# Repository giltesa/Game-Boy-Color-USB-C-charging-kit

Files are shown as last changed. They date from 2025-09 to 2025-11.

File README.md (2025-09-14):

# Game Boy Color USB-C Charging Kit

The **Game Boy Color USB-C Charging Kit** is a circuit that allows you to charge a **Nintendo Game Boy Color** by **USB-C** and use a **Li-ion** battery instead of AA batteries.

This circuit includes the famous **TP4056** and **DW01A**. The first one is the device in charge of charging the battery, and the second one is protecting the lifetime of the battery of the over-discharge.

This kit includes two boards. If you want to install it easy, it's enough with the main board which doesn't need any cable for working. However, if you want to have the status LEDs in the same place as the original status LED, then you will need to solder the second board and joint both with 3 cables. You can choose the best option for you.

This is the maind board:

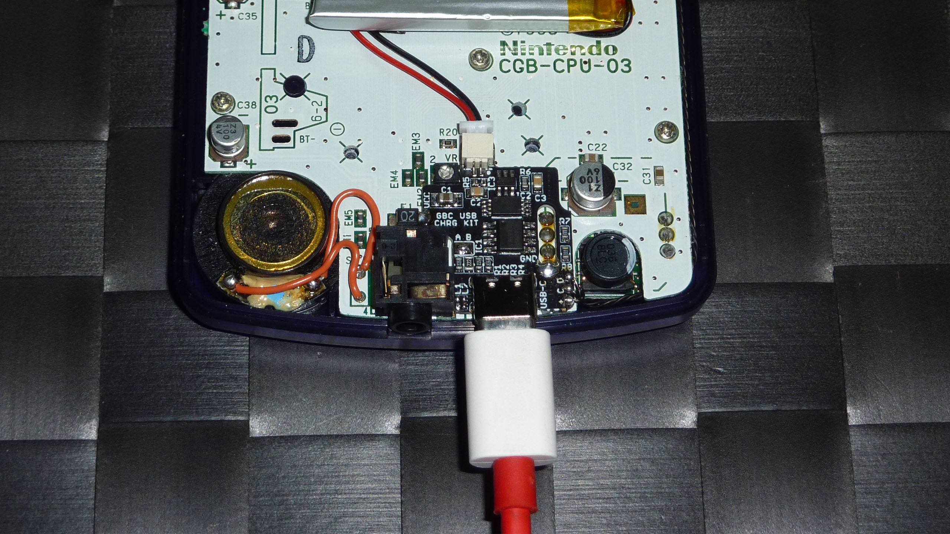
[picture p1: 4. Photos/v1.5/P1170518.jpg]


And this one is the LED board:

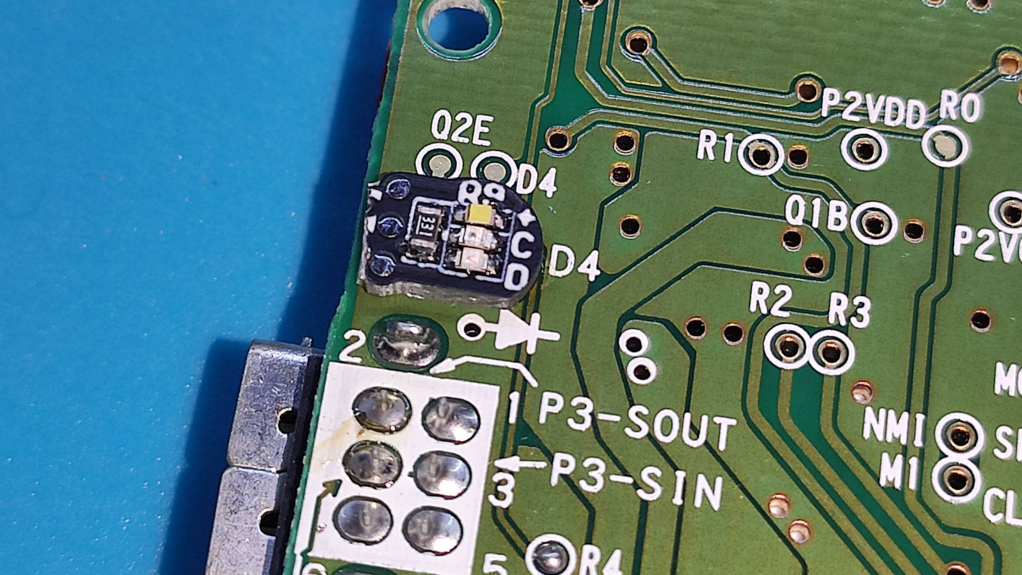
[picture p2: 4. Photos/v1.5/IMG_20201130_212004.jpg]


## Youtube:

Game Boy Color USB-C Charging Kit (Installation)

GBC (https://www.youtube.com/watch?v=6jVHuUIQE74)

A small demostration about how this works:

*(red light = charging, green light = finish to charge, white = GBC is power on)*

GBC (https://www.youtube.com/watch?v=vwyqkQ_spI8)

Battery test: 1500 mAh = 8h 40m

GBC (https://www.youtube.com/watch?v=jIQpzhPCvvI)

## Would you like it?

https://shop.giltesa.com/product/game-boy-color-usb-c-charging-kit/

## More

- [giltesa.com](https://giltesa.com "giltesa.com")
- [twitter.com](https://twitter.com/giltesa "twitter.com")

## License

This project is licensed under a **Creative Commons** license:
**[Attribution-NonCommercial-ShareAlike 4.0 International (CC BY-NC-SA 4.0) ](https://creativecommons.org/licenses/by-nc-sa/4.0/)**

Check the [LICENSE.md](LICENSE.md) for more information.

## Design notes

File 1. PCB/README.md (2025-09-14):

# Source Code Availability Notice

The source code for the electronic circuits previously shared in this repository is **no longer publicly available**.

This decision has been made due to repeated misuse of the shared materials by third parties who have used the code to manufacture and sell products derived from this work for commercial gain, in violation of the license under which it was originally shared.

The original license explicitly **prohibits commercial use** of this work without proper authorization. Unfortunately, the terms of the license were not respected, which undermines the purpose of sharing the source code and the trust of the community.

Thank you for your understanding and respect for intellectual property rights.

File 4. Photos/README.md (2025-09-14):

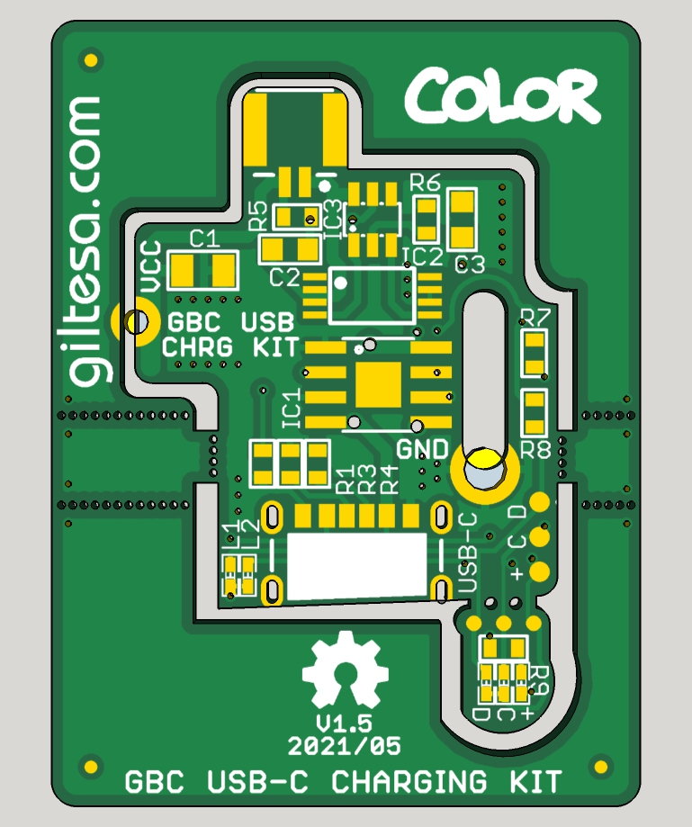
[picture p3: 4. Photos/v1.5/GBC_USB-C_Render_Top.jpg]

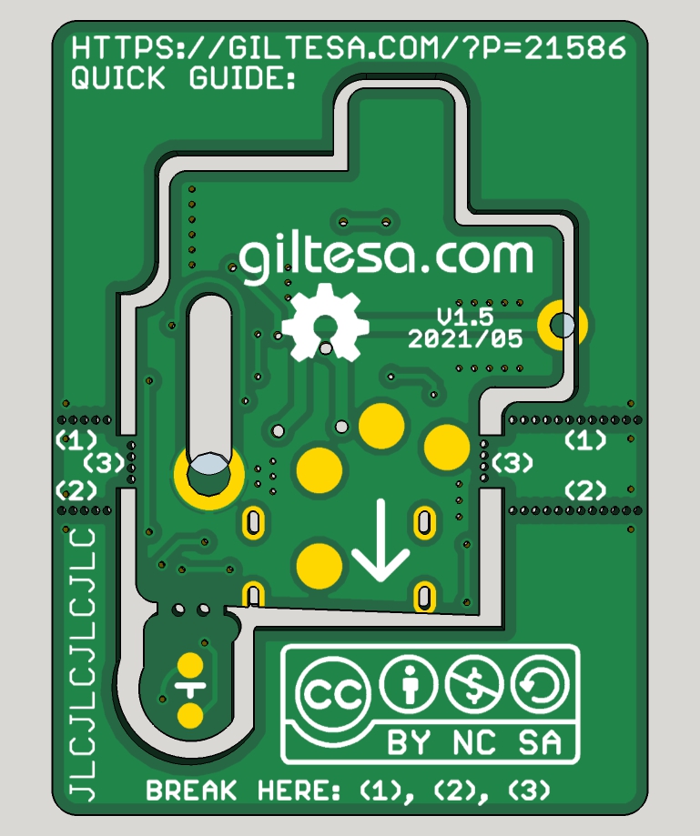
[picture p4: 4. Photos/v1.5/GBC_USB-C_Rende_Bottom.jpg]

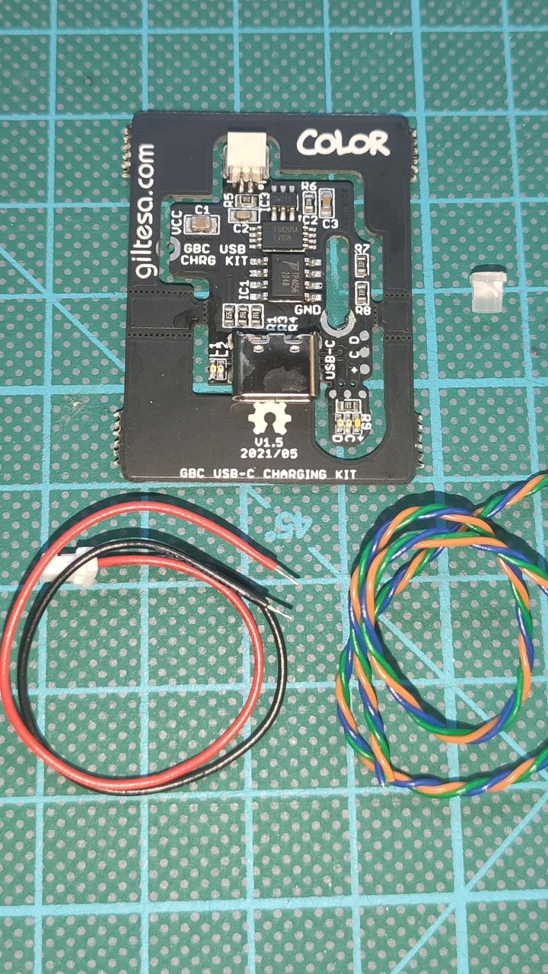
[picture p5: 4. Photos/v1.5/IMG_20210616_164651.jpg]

GBC
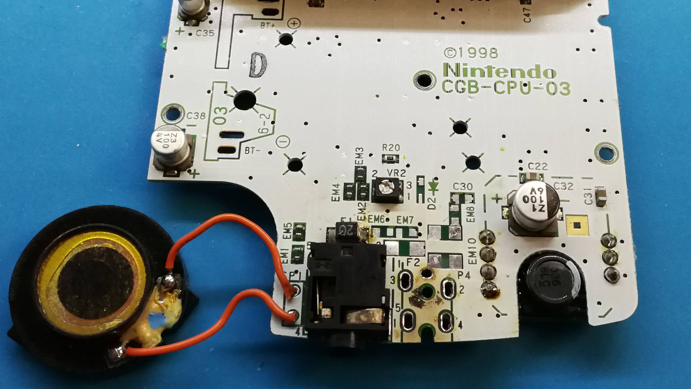
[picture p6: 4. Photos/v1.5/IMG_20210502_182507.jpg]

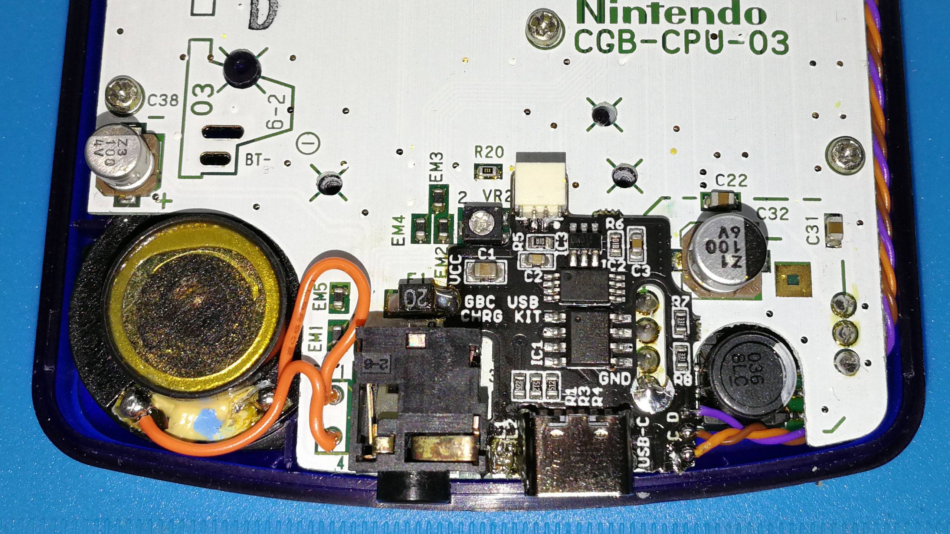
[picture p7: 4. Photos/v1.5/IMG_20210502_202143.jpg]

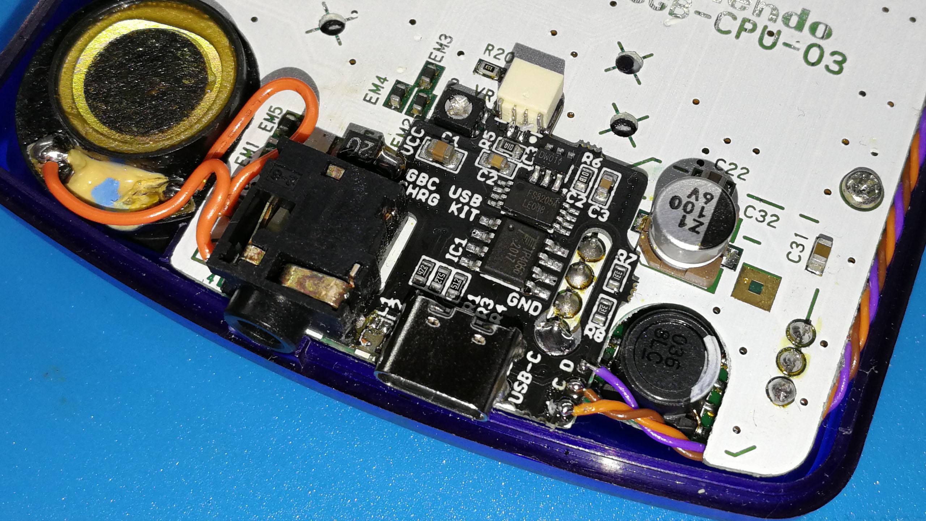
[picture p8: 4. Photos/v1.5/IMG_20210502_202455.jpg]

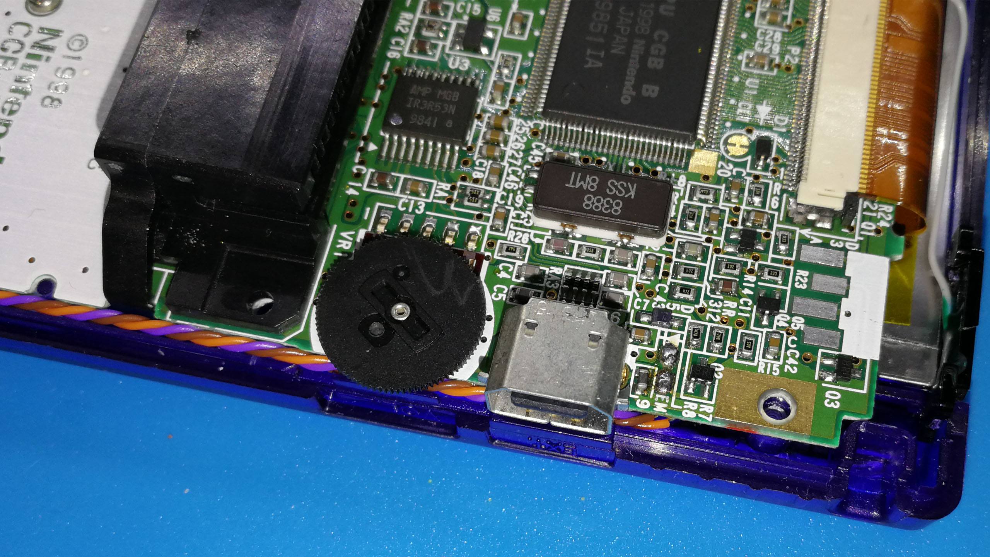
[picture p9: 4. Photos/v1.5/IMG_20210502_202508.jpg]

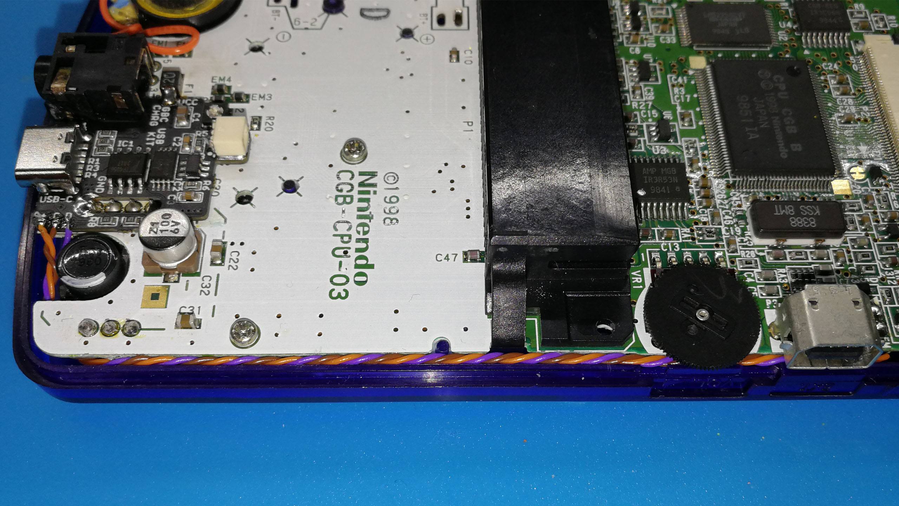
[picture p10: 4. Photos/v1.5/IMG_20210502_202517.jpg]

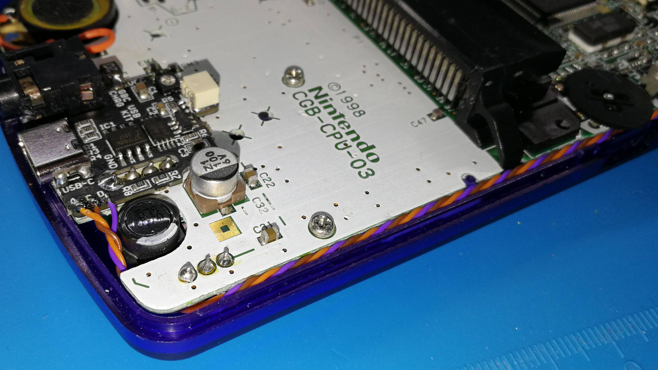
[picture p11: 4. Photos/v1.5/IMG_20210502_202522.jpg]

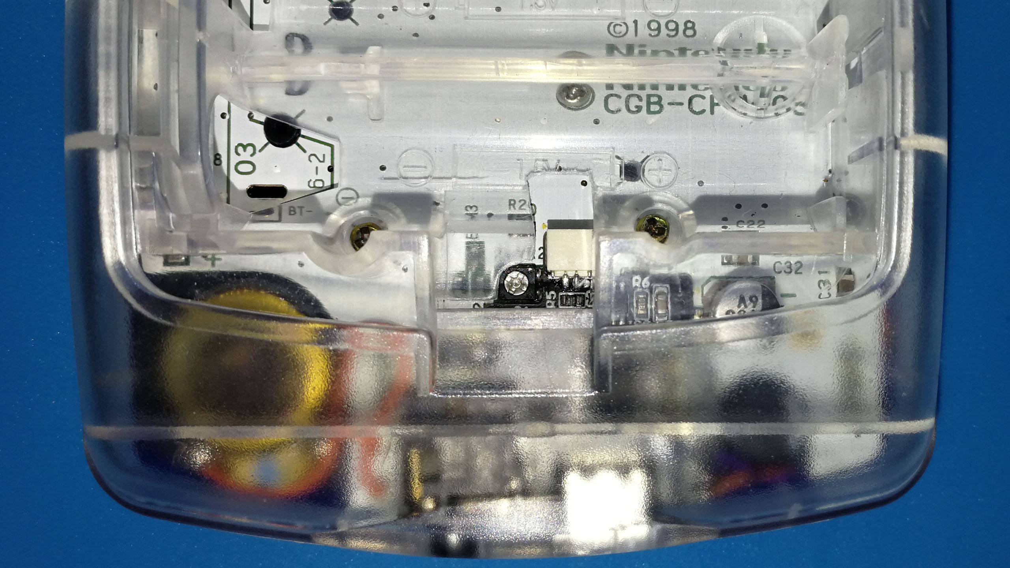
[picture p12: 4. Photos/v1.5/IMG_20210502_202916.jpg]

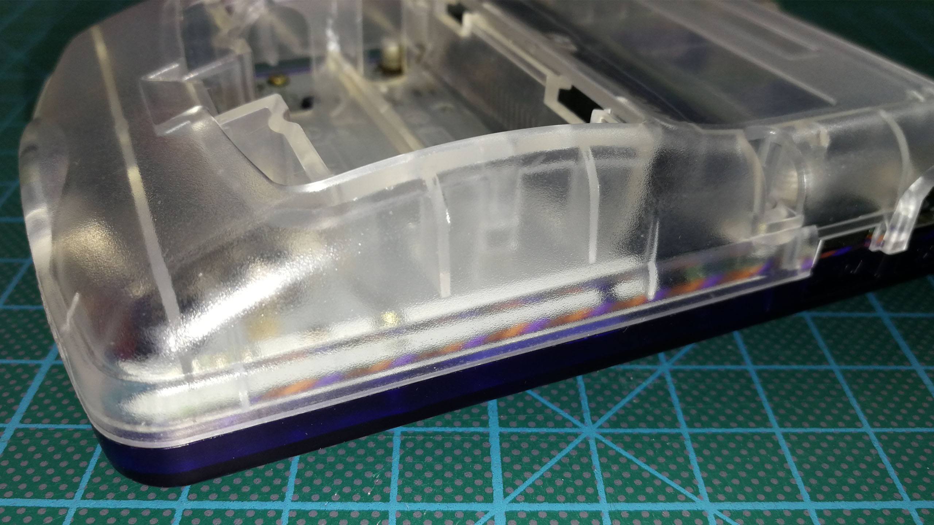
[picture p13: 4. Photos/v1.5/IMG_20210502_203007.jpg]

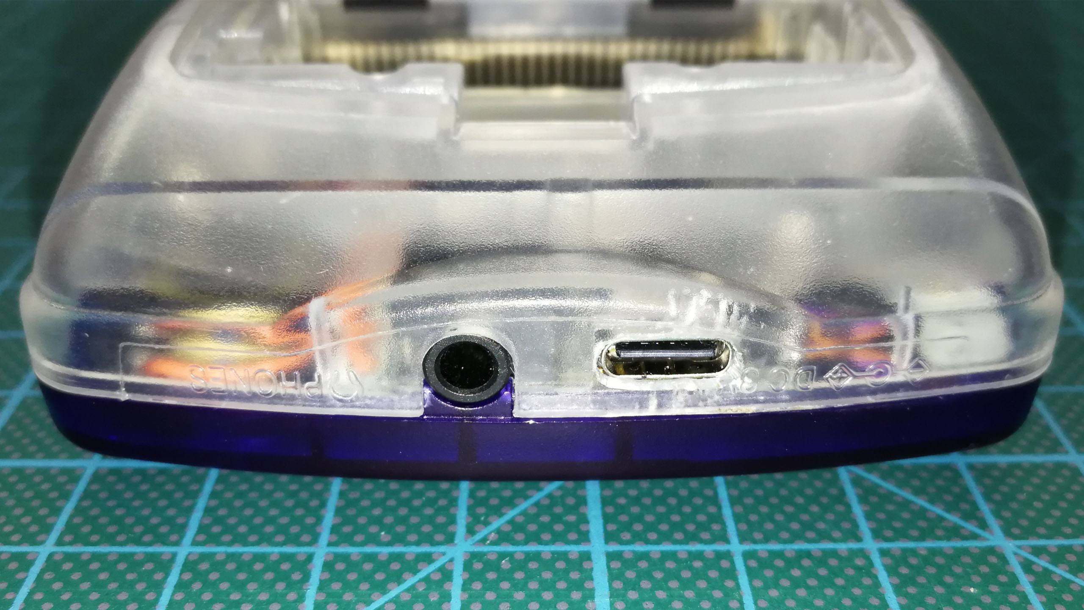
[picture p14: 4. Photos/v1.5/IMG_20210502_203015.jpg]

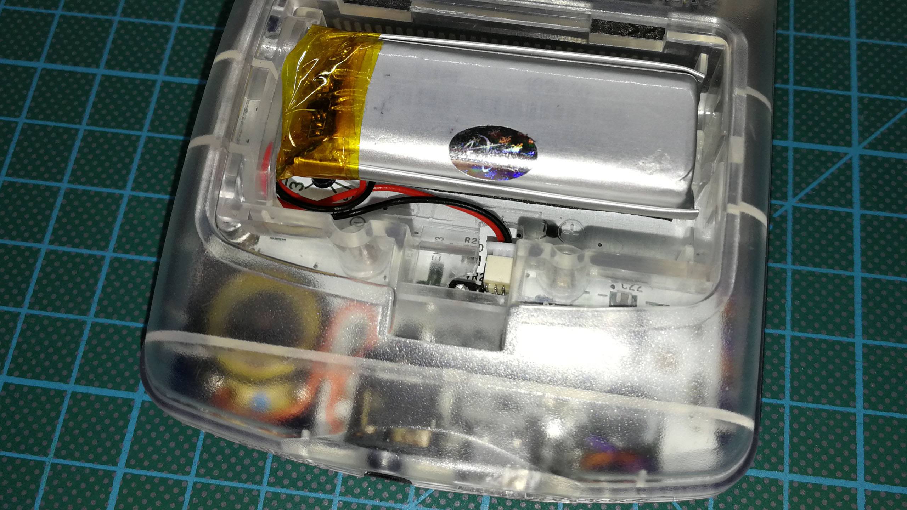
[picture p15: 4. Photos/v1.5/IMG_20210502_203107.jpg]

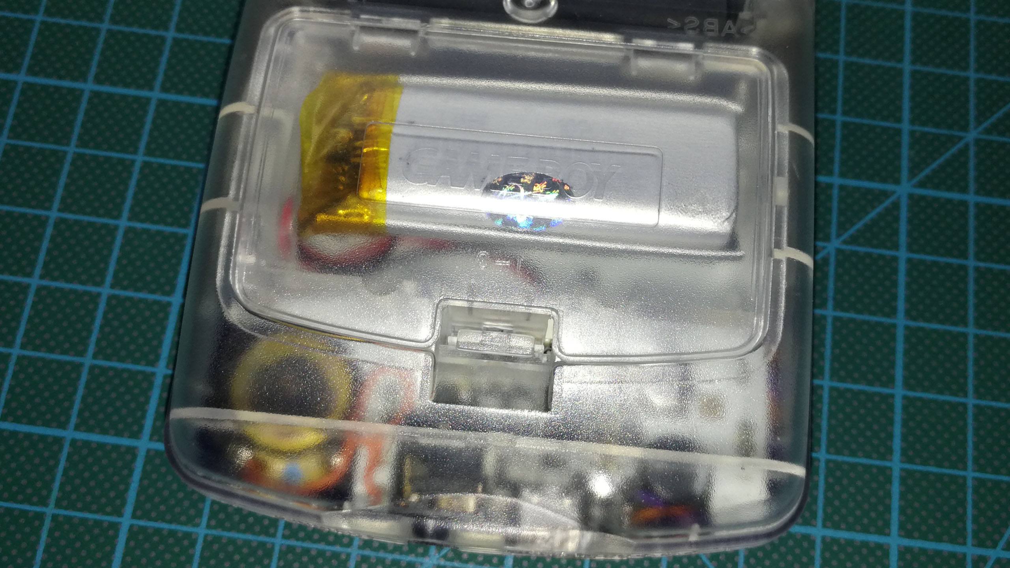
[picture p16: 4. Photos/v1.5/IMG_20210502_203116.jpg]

GBC

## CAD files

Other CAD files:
2. Renders, 3D models/GBC USB-C Charging Kit v1.6 frame.skp
2. Renders, 3D models/GBC USB-C Charging Kit v1.6.skp
2. Renders, 3D models/GBC USB-C Charging Kit v1.7 - Board.skp
2. Renders, 3D models/GBC USB-C Charging Kit v1.7-Black.skp
2. Renders, 3D models/GBC USB-C Charging Kit v1.7.skp
2. Renders, 3D models/GBC USB-C Charging Kit v2.0-Black.skp

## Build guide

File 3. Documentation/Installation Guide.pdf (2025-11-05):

# USB-C charging kit for GAME BOY COLOR

PRODUCT v2.0+

HTTPS://SHOP.GILTESA.COM/PRODUCT/GAME-BOY-COLOR-USB-C-CHARGING-KIT

# PLEASE READ THROUGH THESE INSTRUCTIONS

ENTIRELY BEFORE ATTEMPTING TO INSTALL.

# WARNING: IF YOU ARE NOT COMFORTABLE WITH SOLDERING, OR PERFORMING ANY STEP IN THIS

GUIDE, DO NOT PERFORM THE INSTALL YOURSELF.

# FIND SOMEONE WHO IS COMFORTABLE TO DO IT FOR

YOU.

INDEX

# Description

The Game Boy Color USB-C Charging Kit is a circuit that allows to charge a Nintendo Game Boy Color by USB-C and use a Li-ion battery instead of AA batteries.

# FEATURES

- Exact shape for Game Boy Color.
- Li-Ion battery charger by USB-C with protection for charging level and over discharge.
- Integrated LED indicators on the main board, next to the USB-C, for charging battery (red) and full battery (green).
- External LED indicators board for playing (white), charging battery (red) and full battery (green). The installation is optional.

# INCLUDED

- 1 frame panel which includes the two boards:
- Main board.
- Light board.
- 1 Battery cable.
- 1 Cable of 2 wires for connecting the light board.
- 1 Light diffuser pipe.

# Recommended / REQUIRED (NOT INCLUDED)

- 3.7V li-ion battery (for example 102050 (https://www.aliexpress.com/item/4000036271843.html) or 123048) (https://www.aliexpress.com/item/1005001308043027.html)
- Tri-wing and phillips screwdriver
- Tweezers
- Cutter
- Cutting plier
- Soldering iron
- Tin
- Flux
- Desoldering pump
- Desoldering mesh
- Isopropyl alcohol
- Instant glue (Loctite, Super Glue)

# Board details

There are many pads on the charging board that need to be soldered to join it to the GBC mainboard. The following explains what each pad is for.

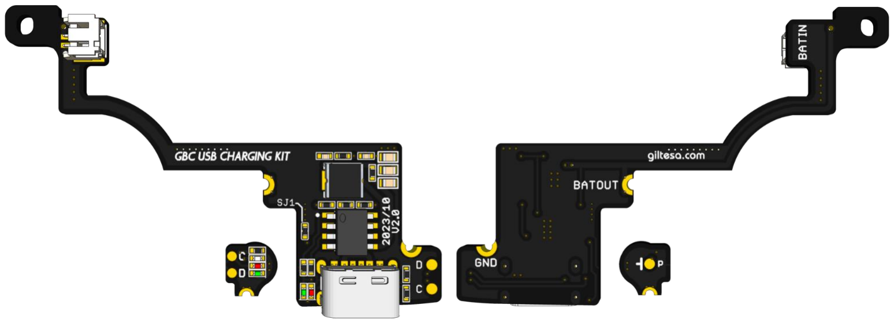
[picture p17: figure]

Main board:

- BATIN: Input connector of the li-ion battery.
- BATOUT: The energy output from battery to the GBC power switch.
- GND: | The ground pad.
- SJ1: | Solder jumper. If you wish, it can be removed to disable the integrated LED indicators.

Light board (optional):

- P: | Power pad for the original LED.
- C: | Charging pads for joining the light and main boards.
- D: | Done pads for joining the light and main boards.
- GND: | The ground pad.

# Test the board

Before starting the installation, you should test the board. If it doesn’t work contact me for a replacement (https://shop.giltesa.com/refund-policy/) (all boards are fully tested, but they may damage during the shipping, we try to package them as better as possible), if this work, go ahead with the installation.

First cut the frame bridges (see photo), then you will be able to connect the USB-C cable, into the GBC USB-C board, and battery. Wait until the light turns green (Even if the battery is already fully charged, it can take 5-10 minutes to detect it and switch to green), indicating that the battery is fully charged.

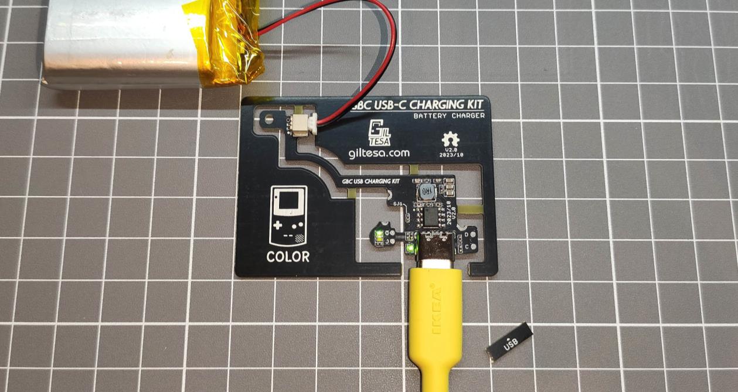
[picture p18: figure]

Second, If the board works as expected you can cut the bridges to separate the main board from the frame (see photo). It’s recommendable separate the rest of the boards during the installation to avoid lose them.

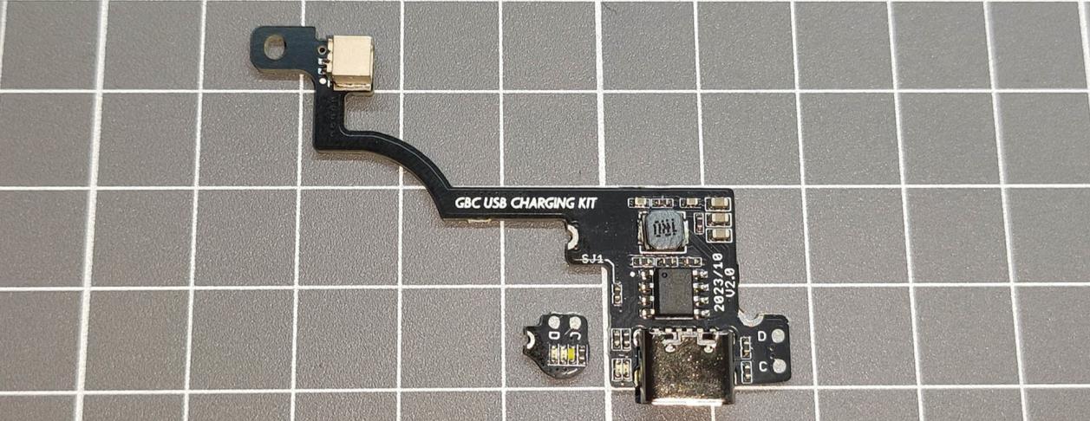
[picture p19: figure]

# INSTALLATION STEPS

Please, carefully read the following steps for a successful installation.

## Pre installation Steps

Before the installation, your GBC may need some extra steps to have it ready for the kit.

1. Disassembly the Game Boy Color

Nintendo products in general use two kind of screws. The first one called tri-wing to close the shell, and the second one called phillips to hold the main board to the shell.

Use the tri-wing screwdriver to open the shell and remove the 6 tri-wing screws.

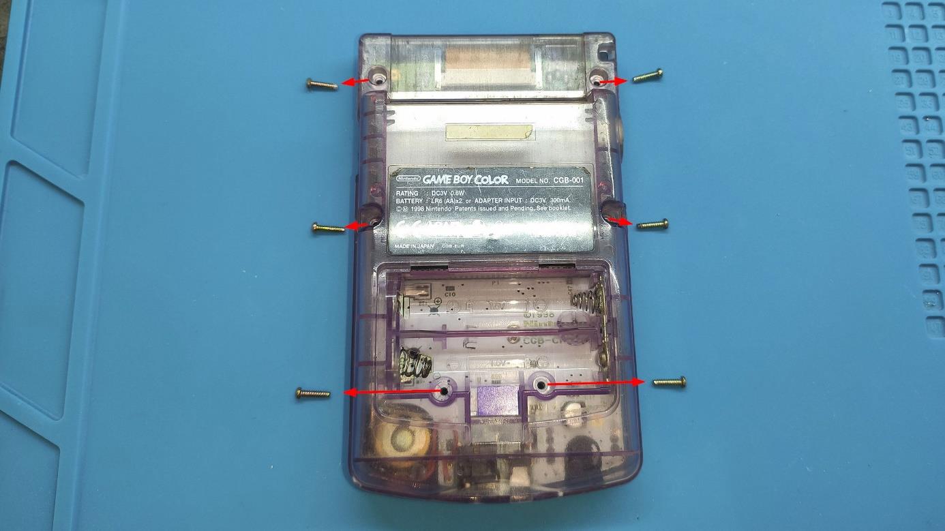
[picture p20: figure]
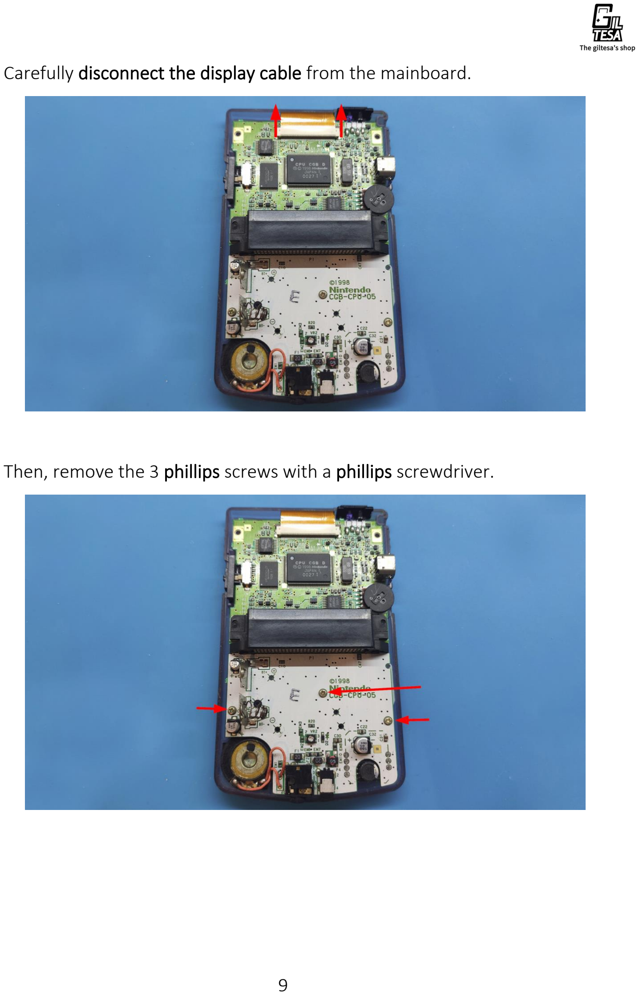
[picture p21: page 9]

Carefully disconnect the display cable from the mainboard.

Then, remove the 3 phillips screws with a phillips screwdriver.

2. Cleaning the mainboard

Use isopropyl alcohol to clean the board. Since the board was made in 1998, the board may be full of dust or with the flux from the factory (yellow spots). All this dirt can be cleaned with alcohol.

3. Cleaning the power switch

Depending on how the GBC has been stored, the switch can be also full of dust inside and prevent a good electrical connection. If you see when your turn on the GBC, sometimes it doesn’t turn on well at the first time, this may be the cause.

However, cleaning the power switch is a bit difficult to do. You must be extremely careful about cleaning it or you may damage it.

First, protect the nearby parts with kapton tape to avoid burning them with the soldering iron.

Then, heat the pads, first one and with a tweezer or flat screwdriver pry the veneer apart first on one side, then repeat this on the other side.

You can see it in the following video:

https://youtu.be/P-4KlOvaQ2M

Once the metallic veneer is removed. The switch can be cleaned with alcohol and close and solder it as before.

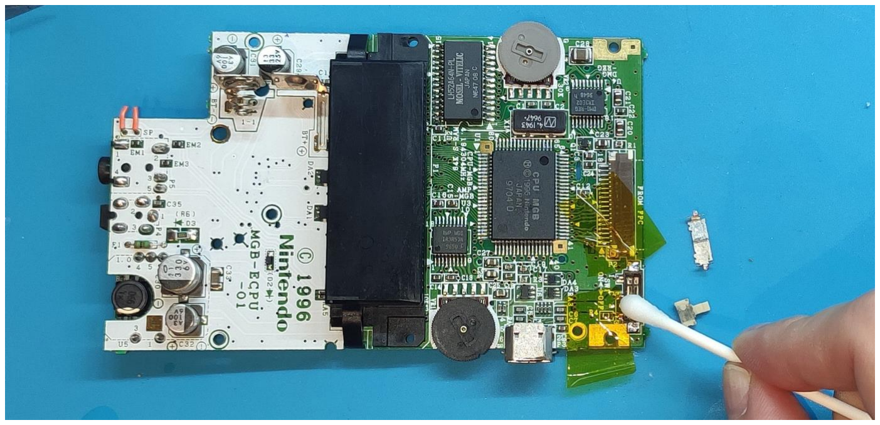
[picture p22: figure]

This is a GB Pocket, but it's the same for GB Color

## installation Steps

1. Protect the button pads

Because many pads need to be soldered and they are next to the button pads. This can cause the buttons pads get dirty with tin and interfere with proper operation. To avoid that, protect them with kapton tape until the installation is completed.

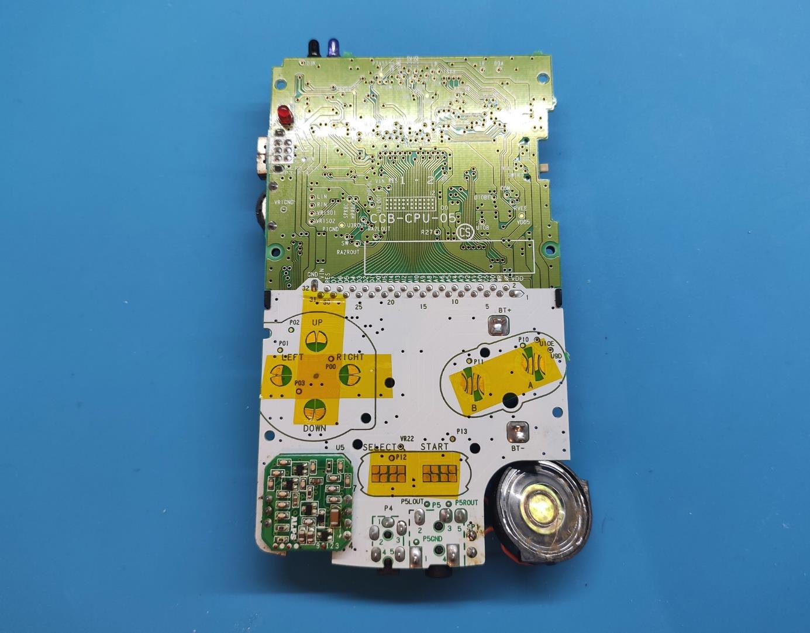
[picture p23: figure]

2. Remove unnecessary components

There are some components that the kit doesn’t need, and they are in the middle where the kit needs to be installed.

Remove the components one by one. You can follow this list from the easier one to the harder one to remove:

- Diodes: D2
- Capacitors: C30
- Coil filter: EM8, EM7, EM6
- Fuses: F2
- Coil filter: EM10
- Red light (optional, only if you want to install the light board of the kit)
- Power plates BT+ and BT- for the AAA batteries.
- DC Jack

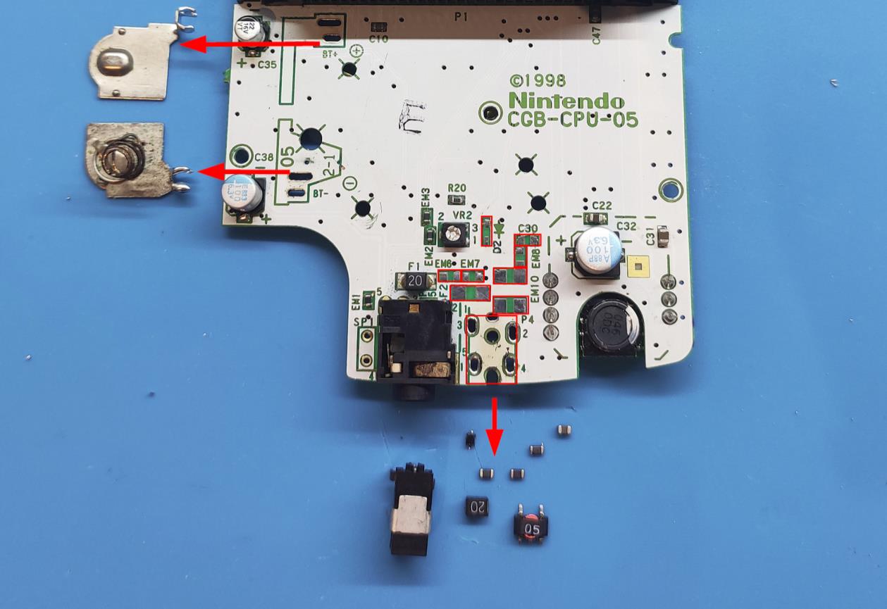
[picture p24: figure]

The speaker doesn’t need to be removed from the mainboard; however, it can help during the installation since it is very annoying. It can be soldered again at the end or better, be replaced for a new one.

3. Clean the excess of tin

All the pads where the components were before need to be clean and free of tin. Otherwise, the kit will not be flat over the GBC mainboard.

Use a desoldering pump or/and flux and desoldering mesh for removing the tin.

4. Clean the board

After the components are removed, it may be dirty, clean it again with isopropyl alcohol.

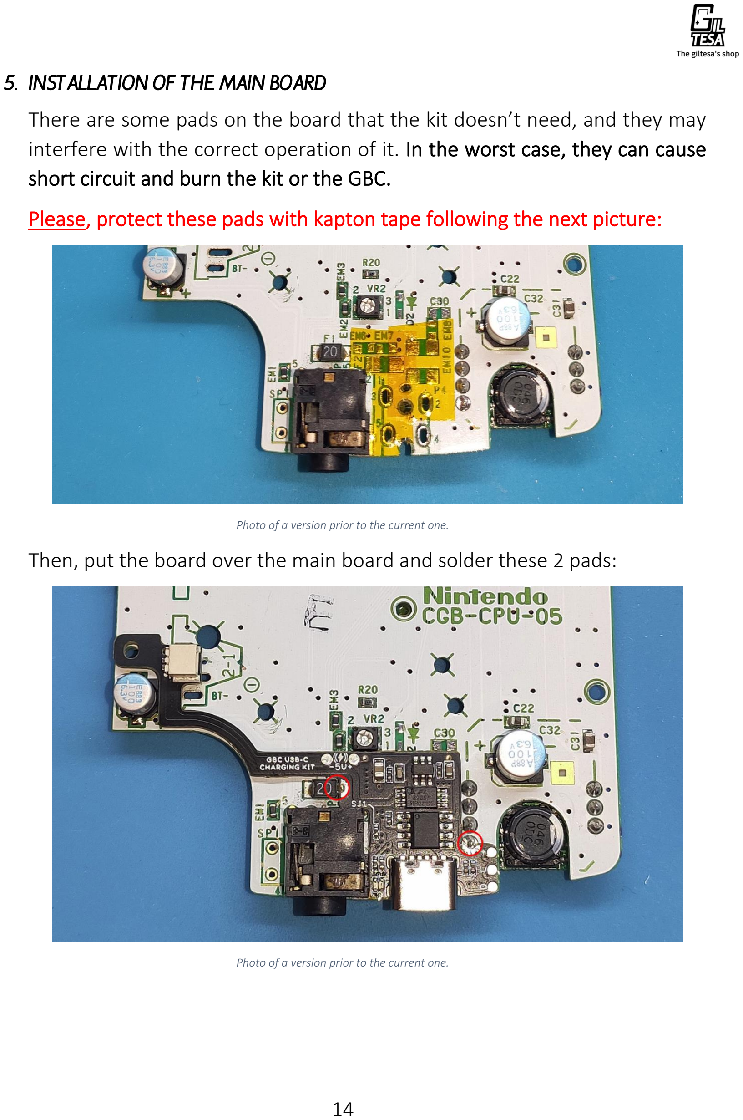
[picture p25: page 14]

5. Installation of the main board

There are some pads on the board that the kit doesn’t need, and they may interfere with the correct operation of it. In the worst case, they can cause short circuit and burn the kit or the GBC.

Please, protect these pads with kapton tape following the next picture:

Photo of a version prior to the current one.
Then, put the board over the main board and solder these 2 pads:

Photo of a version prior to the current one.

6. Installation of the light board (optional)

First you need to remove it. Heat both legs at the same time and then remove it from the mainboard.

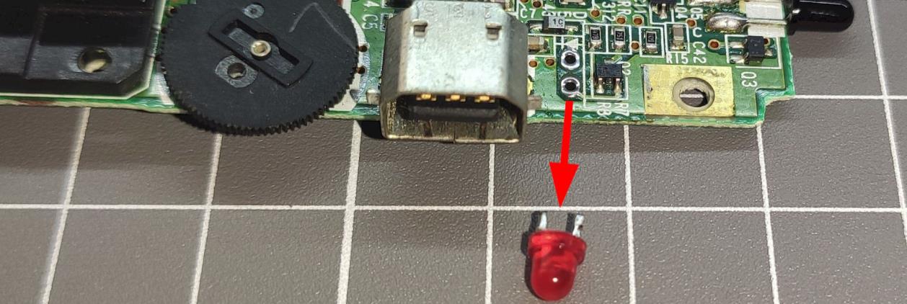
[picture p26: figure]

The best way to solder the light board is by pre-soldering the pad on the underside first. Then, place the board onto the GBC mainboard and heat the pad from the opposite side. The solder will melt, and the light board will be joined together.

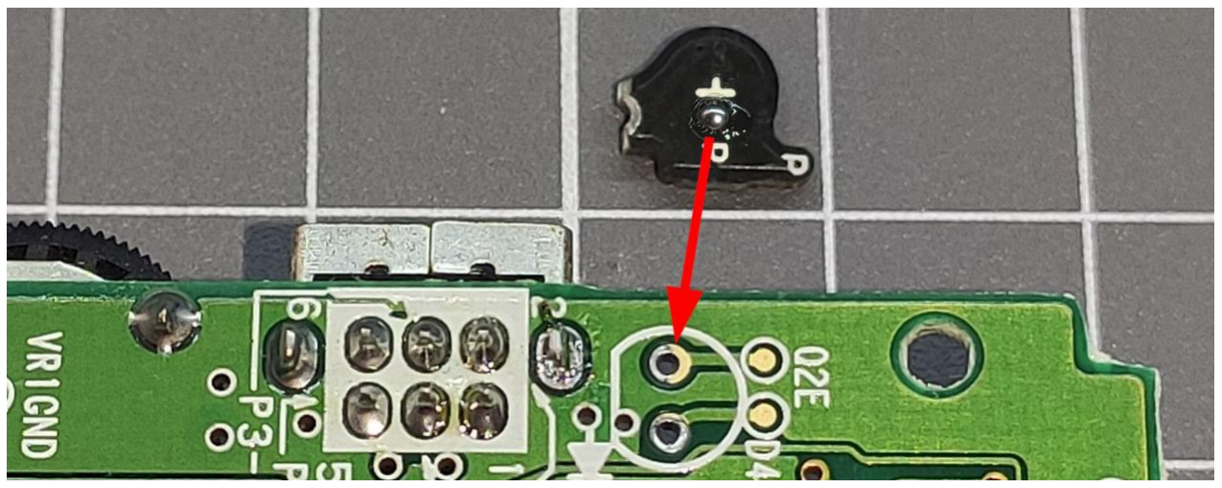
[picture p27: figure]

Now solder the pad on the bottom of the board. You need to connect it to one of the legs of the Link connector.

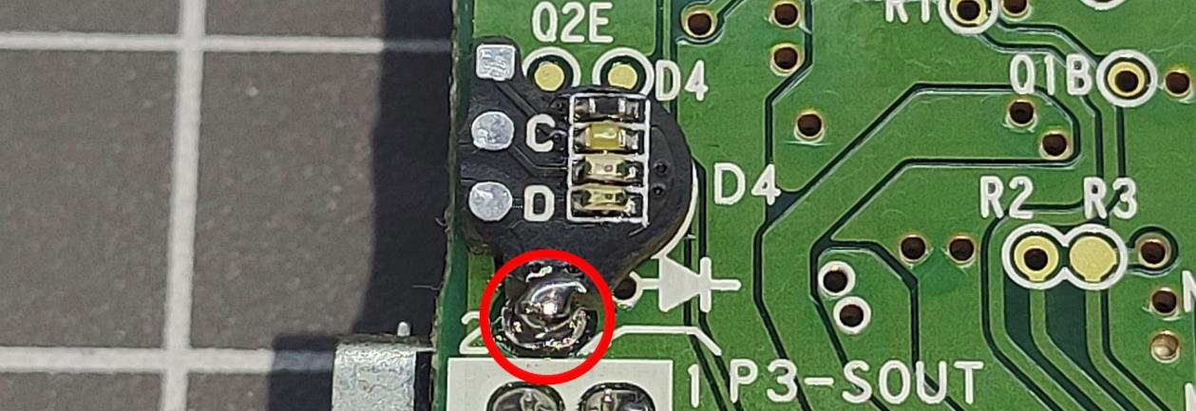
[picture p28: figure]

This photo corresponds to a GBP; it's the same for the GBC.
If you wish, you can now verify that the white light of the light board is functioning correctly and that both soldering joints are well done.

Select the diode measurement mode on your multimeter and place it in this position:

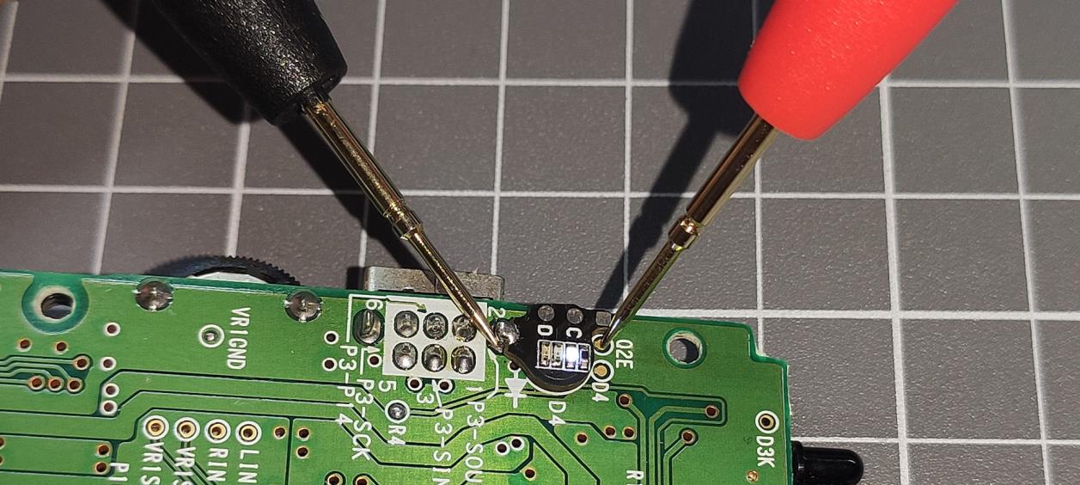
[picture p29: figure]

Once the light board is installed, all that remains is to solder the two-wire cable included with the kit. You should connect the C pads and the D pads respectively. The color of the cables may vary, but what's important is that the C pad on the light board is connected to the C pad on the main board, and the D is connected to the D pad.

The cable is about 3 or 4 cm longer than necessary; you can start soldering it from the light board and cut the excess later:

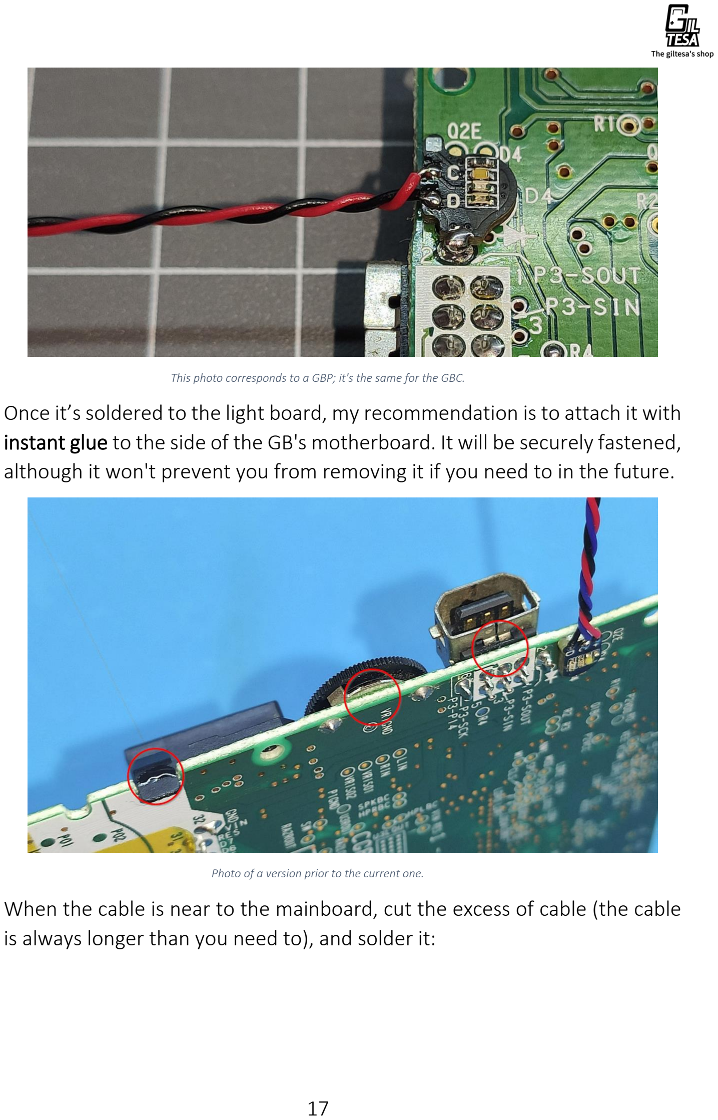
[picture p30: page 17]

This photo corresponds to a GBP; it's the same for the GBC.
Once it’s soldered to the light board, my recommendation is to attach it with instant glue to the side of the GB's motherboard. It will be securely fastened, although it won't prevent you from removing it if you need to in the future.

Photo of a version prior to the current one.
When the cable is near to the mainboard, cut the excess of cable (the cable is always longer than you need to), and solder it:

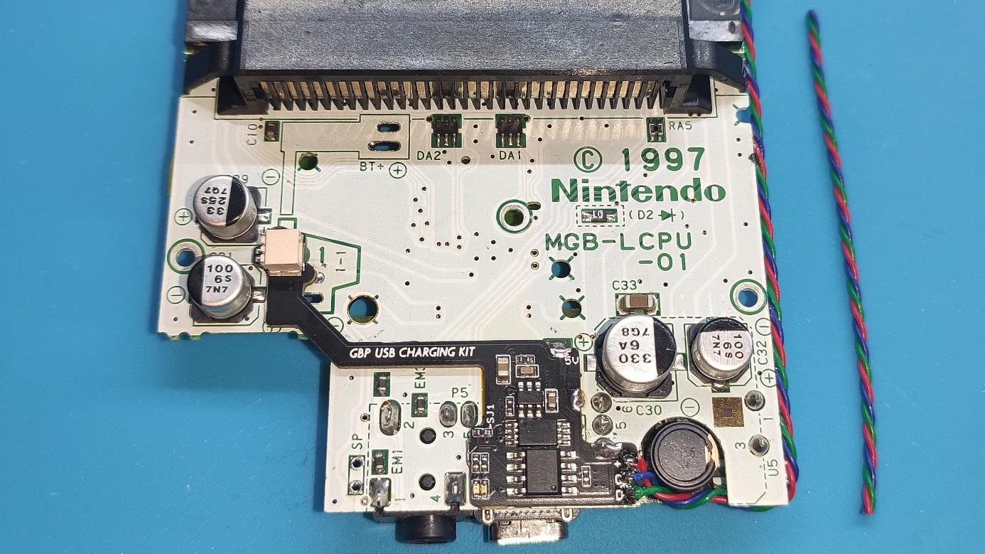
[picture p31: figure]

This is a GB Pocket, but it's the same for GB Color

Once at this point, you can assembly everything except the bottom shell than need to be trimmed in the next step.

So, install the screen, light diffuser included with the kit, bottoms, and mainboard. You can also test the board with USB-C cable and the battery, check the lights works well.

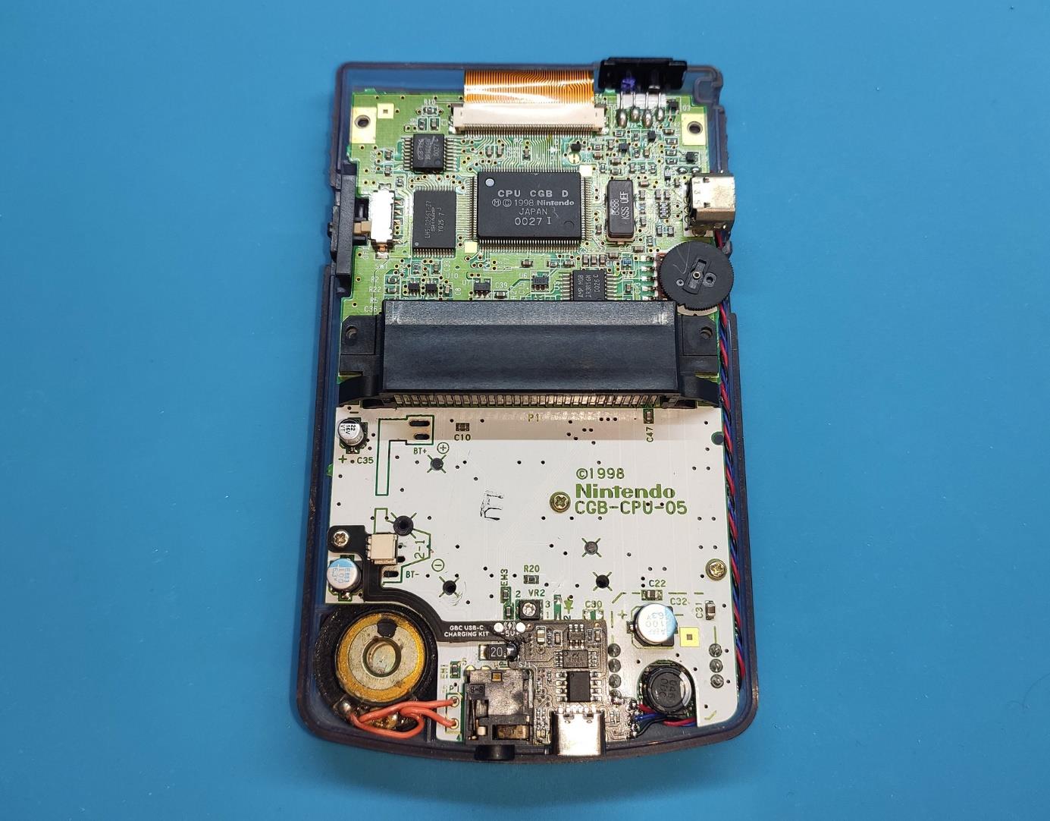
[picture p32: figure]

7. Cutting the plastic shell

The GBC board has been designed to try to cut into the shell as less as possible. However, there are some parts that need to be cut/trim.

Inside the shell
This part touches the main circuit, trim it:

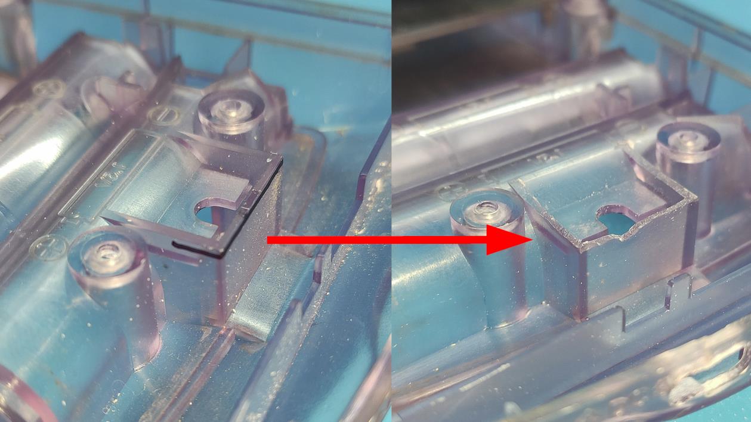
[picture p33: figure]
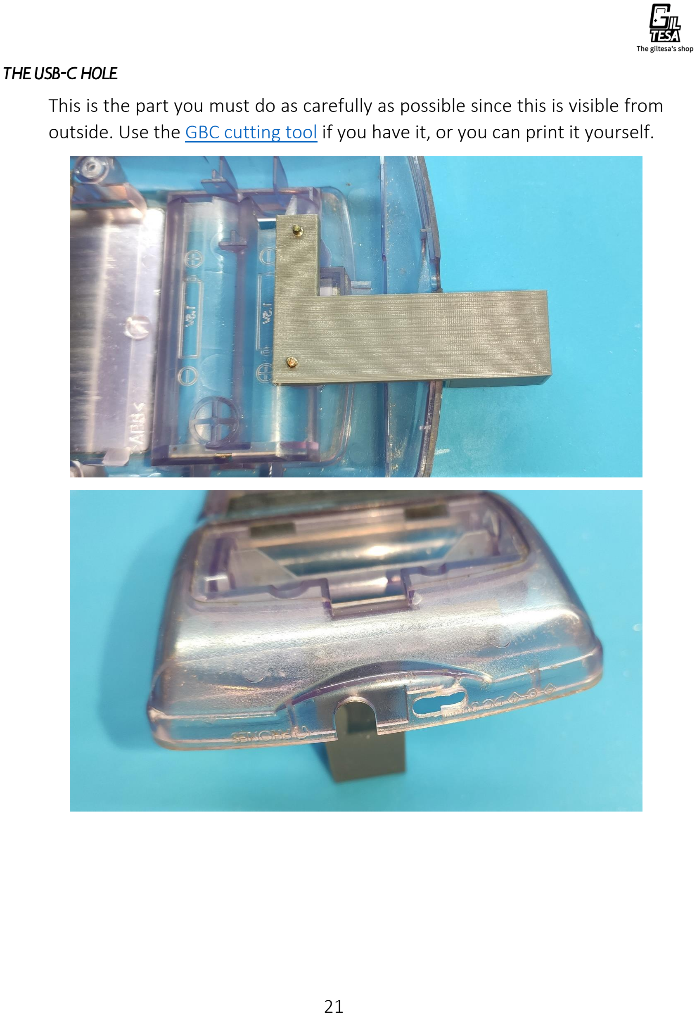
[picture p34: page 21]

The usb-C hole
This is the part you must do as carefully as possible since this is visible from outside. Use the GBC cutting tool (https://shop.giltesa.com/product/game-boy-color-usb-c-cutting-tool/) if you have it, or you can print it yourself.

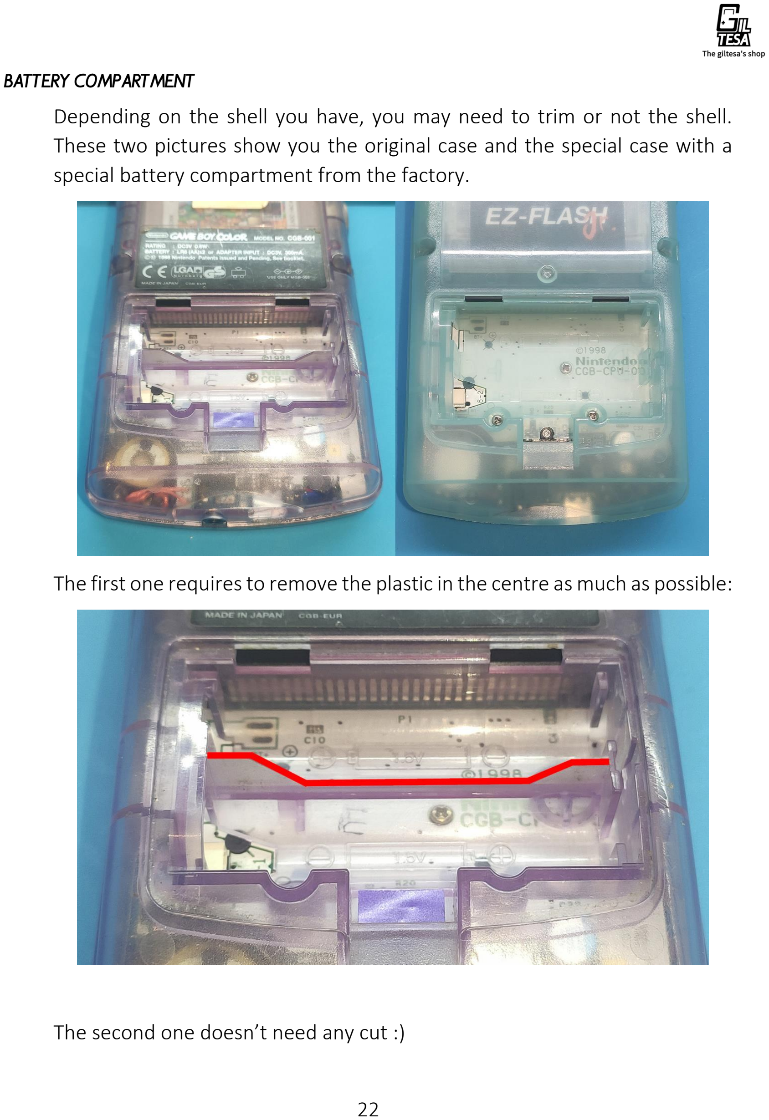
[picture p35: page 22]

Battery compartment
Depending on the shell you have, you may need to trim or not the shell. These two pictures show you the original case and the special case with a special battery compartment from the factory.

The first one requires to remove the plastic in the centre as much as possible:

The second one doesn’t need any cut :)

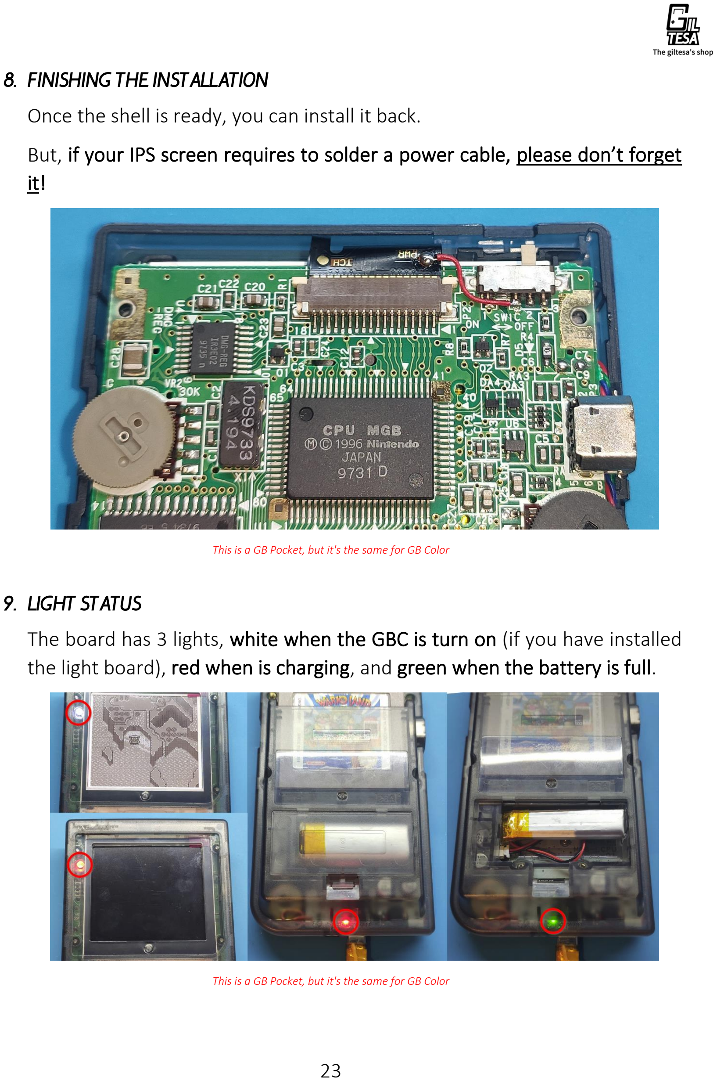
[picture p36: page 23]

8. Finishing the installation

Once the shell is ready, you can install it back.

But, if your IPS screen requires to solder a power cable, please don’t forget it!

This is a GB Pocket, but it's the same for GB Color

9. Light status

The board has 3 lights, white when the GBC is turn on (if you have installed the light board), red when is charging, and green when the battery is full.

This is a GB Pocket, but it's the same for GB Color

10.Battery cable

If your battery includes the appropriate battery connector, you just need to connect it to the GBC, otherwise you will need to replace the battery cable for the provided one with the kit.

The easy way is to splice the original wires with the new ones and use kapton tape to protect the joint.

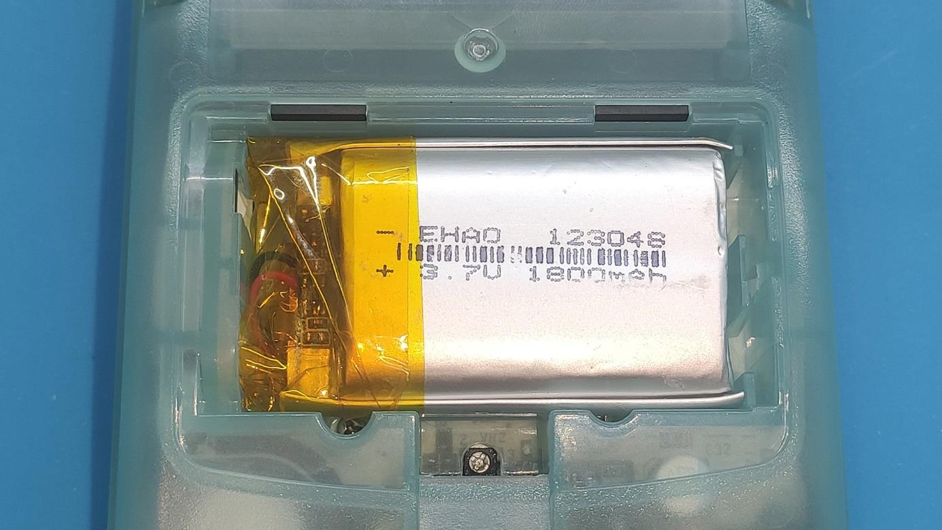
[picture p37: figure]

If you are comfortable soldering, you can replace the whole old cable and solder the new one directly to the battery.

The following explains step-by-step how to do it for the Game Boy DMG battery. The steps are the same for the GBC, only the battery size changes.

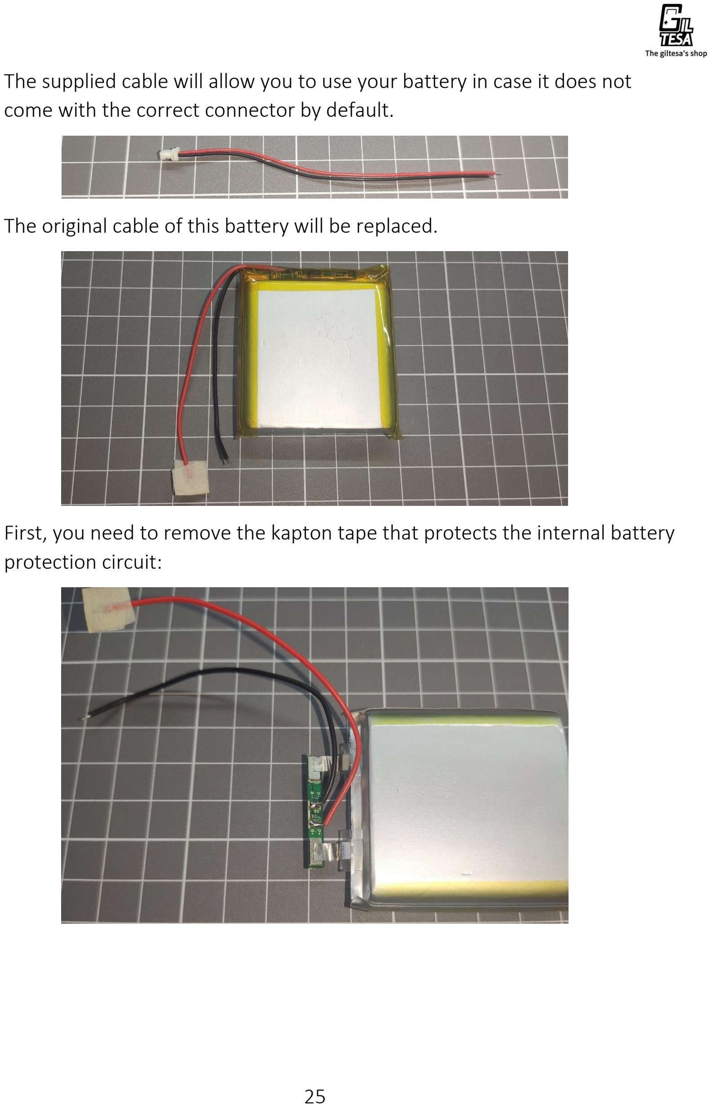
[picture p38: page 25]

The supplied cable will allow you to use your battery in case it does not come with the correct connector by default.

The original cable of this battery will be replaced.

First, you need to remove the kapton tape that protects the internal battery protection circuit:

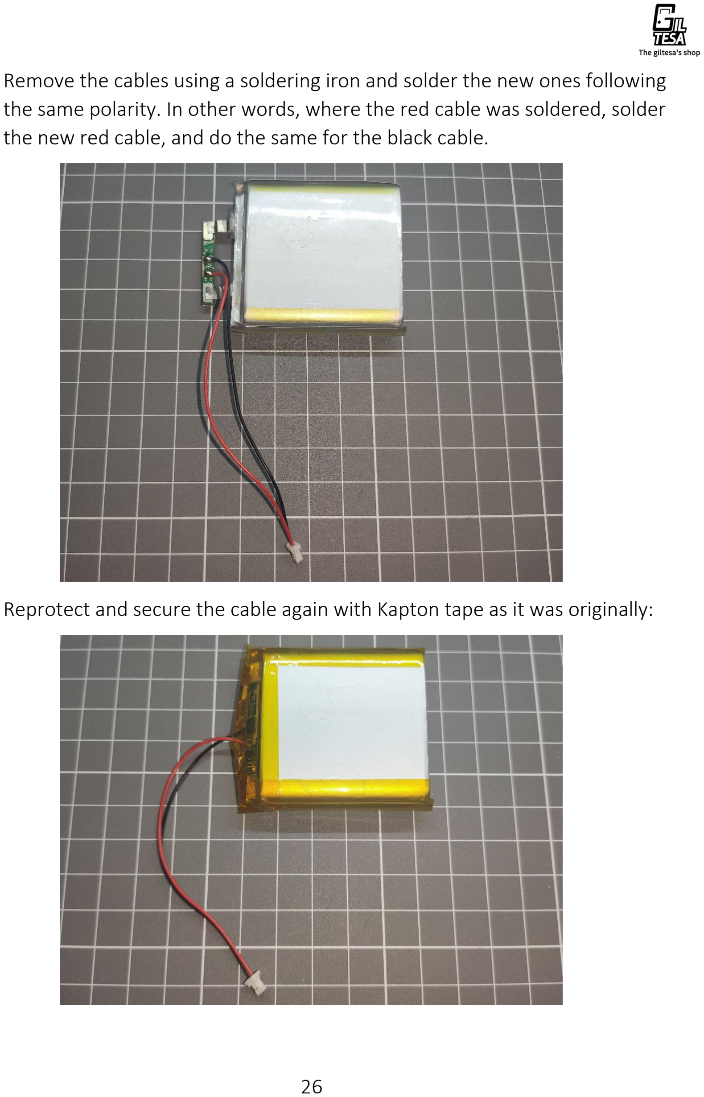
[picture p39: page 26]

Remove the cables using a soldering iron and solder the new ones following the same polarity. In other words, where the red cable was soldered, solder the new red cable, and do the same for the black cable.

Reprotect and secure the cable again with Kapton tape as it was originally:

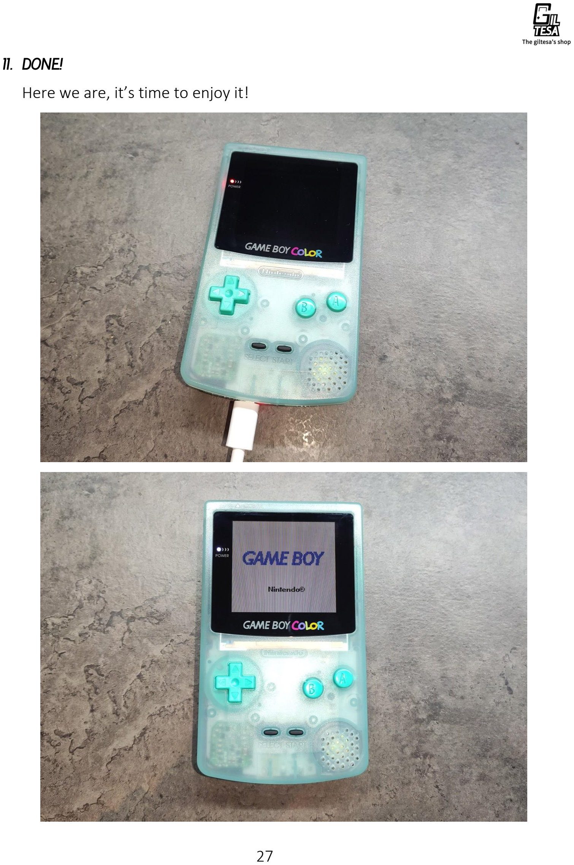
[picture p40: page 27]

11. Done!

Here we are, it’s time to enjoy it!

## Frequently Asked Questions- FAQ

1. What charger can be used?
You can use any standard charger for mobile phones, computers, etc., with 5V 1A. It doesn't need to be a Power Delivery charger since this feature is not used. Of course, if you want to use a Power Delivery charger, there's no problem or risk.

Technical data for curious minds:

Power Delivery chargers can supply a wide range of voltages: 5V, 9V, 12V, 15V, and 20V. However, for this to happen, the device must communicate with the charger to explicitly request the desired voltage. Without this communication, the charger will never supply more than 5V. That's one of the advantages of USB-C, as it can be used with both old and modern devices.

2. The green light does not turn on. How do the lights work?
The white light turns on and off when you turn the console on and off, indicating the battery status. Its brightness will decrease as the battery drains. Therefore, it serves the function of the original red light.

The new red light, along with the green light, indicates the battery's charging status. When the light is red, it means the battery is charging. Once the battery is fully charged, the light will change to green.

If the battery is already charged and you reconnect it via USB, the circuit will check the charge, and after a few minutes, perhaps up to 10 minutes, it will indicate again with the green light that the battery is charged.

If the green light never turns on, try doing several charge and discharge cycles with the battery. This involves fully discharging the battery until the console turns off, then charging it until the light turns green (or for several hours), and repeating the process once more. Let's say that calibrates the battery.

3. The GBC doesn’t turn on.
If you have replaced the capacitors in your GBC, make sure that the capacity is the same as the original capacitors. Otherwise, this may cause the console not to turn on, or only turn on when connected via USB-C.

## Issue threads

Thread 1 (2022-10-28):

A question

446599, 2022-10-28:
How thick is this board，it doesn't show when I uploading the gerber
thank you very much

giltesa, 2022-10-28:
The board thickness is 1.2mm 🙂

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
